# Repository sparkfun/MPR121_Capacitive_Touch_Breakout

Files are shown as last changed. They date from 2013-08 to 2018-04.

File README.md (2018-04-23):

**NOTE:** *This product has been retired from our catalog. If you are looking for more up-to-date info, please check out some of these resources to see how other users are still hacking and improving on this product.*
* *[SparkFun Forum](https://forum.sparkfun.com/)*
* *[Comments Here on GitHub](https://github.com/sparkfun/MPR121_Capacitive_Touch_Breakout/issues)*
* *[IRC Channel](https://www.sparkfun.com/news/263)*

MPR121 Capacitive Touch Sensor Breakout Board
=============================================

[MPR121 Breakout Board  
*MPR121 Capacitive Touch Sensor Breakout Board (SEN-09695)*](https://www.sparkfun.com/products/9695)

This is a breakout  board for the MPR121QR2. It is a capacitive touch sensor controller driven by an I2C interface. The chip can control
up to twelve individual electrodes, as well as a simulated thirteenth electrode. 

Repository Contents
-------------------
* **/Firmware** - Example Arduino Sketch
* **/Hardware** - All Eagle design files (.brd, .sch)

License Information
-------------------
The hardware is released under [Creative Commons Share-alike 3.0](http://creativecommons.org/licenses/by-sa/3.0/).  
All other code is open source so please feel free to do anything you want with it; you buy me a beer if you use this and we meet someday ([Beerware license](http://en.wikipedia.org/wiki/Beerware)).

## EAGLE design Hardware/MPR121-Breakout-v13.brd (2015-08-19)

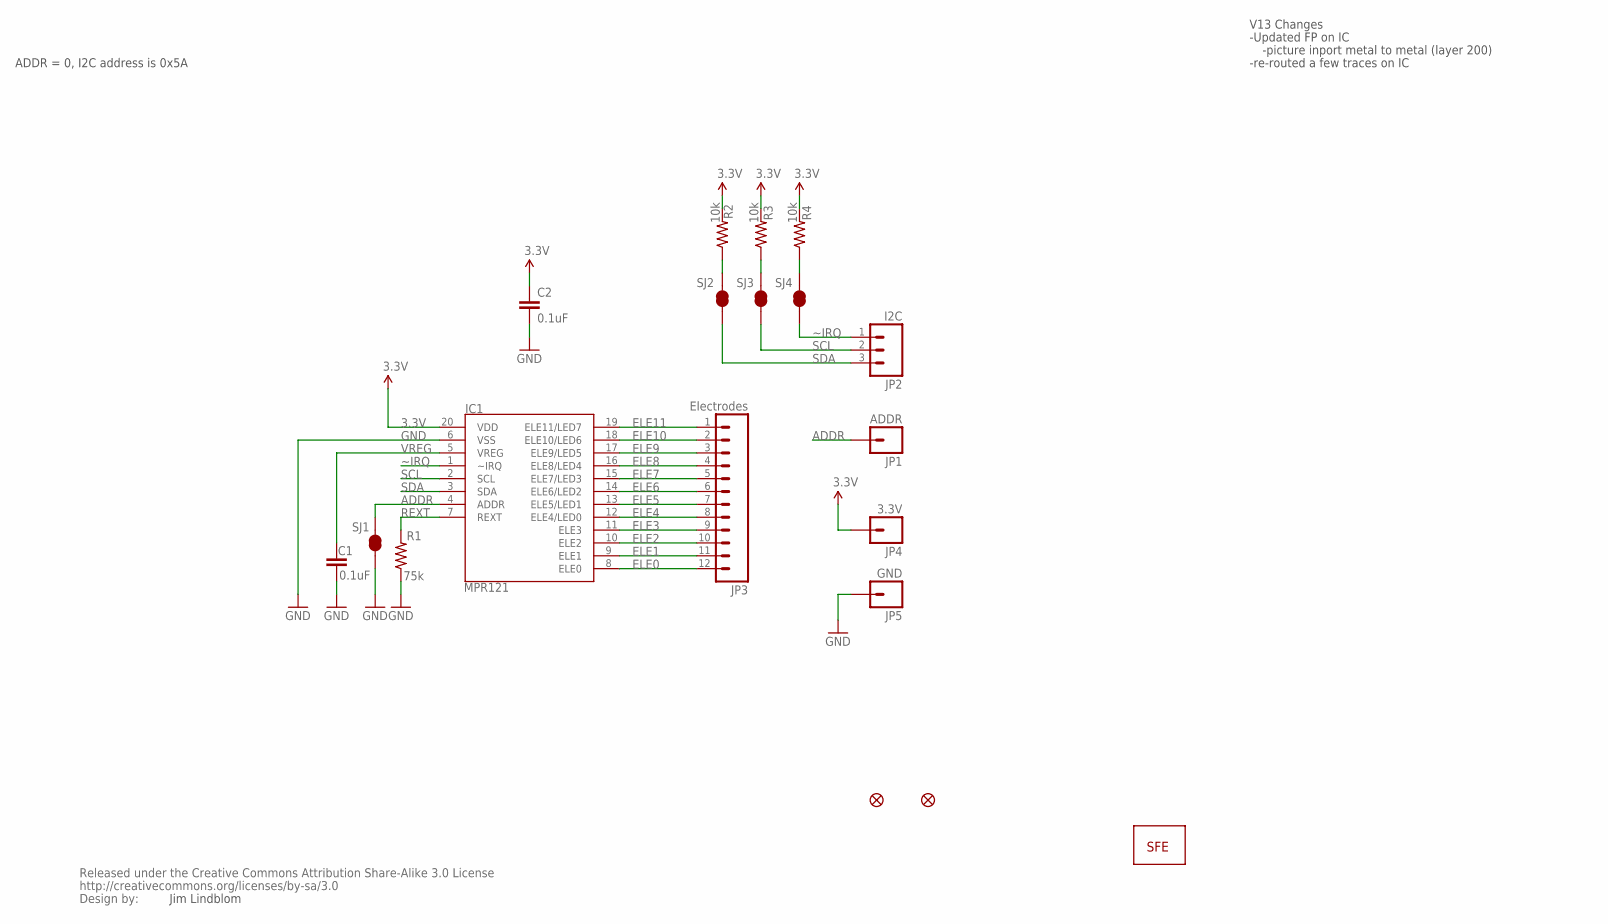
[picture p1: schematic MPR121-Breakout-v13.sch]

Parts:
C1, C2: 0.1uF; 0603-CAP
IC1: MPR121; QFN-20-0.4MM-V2
JP1: ADDR; 1X01
JP2: I2C; 1X03
JP3: Electrodes; 1X12
JP4: 3.3V; 1X01
JP5: GND; 1X01
JP7: LOGO-SFENEW; SFE-NEW-WEBLOGO
JP8, JP9: FIDUCIAL1X2; FIDUCIAL-1X2
R1: 75k; 0603-RES
R2, R3, R4: 10k; 0603-RES
SJ1, SJ2, SJ3, SJ4: SOLDERJUMPERTRACE; SJ_2S-TRACE
U$1: CREATIVE_COMMONS

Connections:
3.3V: C2.1, IC1.20 (VDD), JP4.1, R2.2, R3.2, R4.2
ADDR: IC1.4 (ADDR), JP1.1, SJ1.2
ELE0: IC1.8 (ELE0), JP3.12
ELE1: IC1.9 (ELE1), JP3.11
ELE2: IC1.10 (ELE2), JP3.10
ELE3: IC1.11 (ELE3), JP3.9
ELE4: IC1.12 (ELE4/LED0), JP3.8
ELE5: IC1.13 (ELE5/LED1), JP3.7
ELE6: IC1.14 (ELE6/LED2), JP3.6
ELE7: IC1.15 (ELE7/LED3), JP3.5
ELE8: IC1.16 (ELE8/LED4), JP3.4
ELE9: IC1.17 (ELE9/LED5), JP3.3
ELE10: IC1.18 (ELE10/LED6), JP3.2
ELE11: IC1.19 (ELE11/LED7), JP3.1
GND: C1.2, C2.2, IC1.6 (VSS), JP5.1, R1.1, SJ1.1
REXT: IC1.7 (REXT), R1.2
SCL: IC1.2 (SCL), JP2.2, SJ3.1
SCL_PU: R3.1, SJ3.2
SDA: IC1.3 (SDA), JP2.3, SJ2.1
SDA_PU: R2.1, SJ2.2
VREG: C1.1, IC1.5 (VREG)
~IRQ: IC1.1 (~IRQ), JP2.1, SJ4.1
~IRQ_PU: R4.1, SJ4.2

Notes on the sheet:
ADDR = 0, I2C address is 0x5A
Jim Lindblom
V13 Changes
-Updated FP on IC
-picture inport metal to metal (layer 200)
-re-routed a few traces on IC

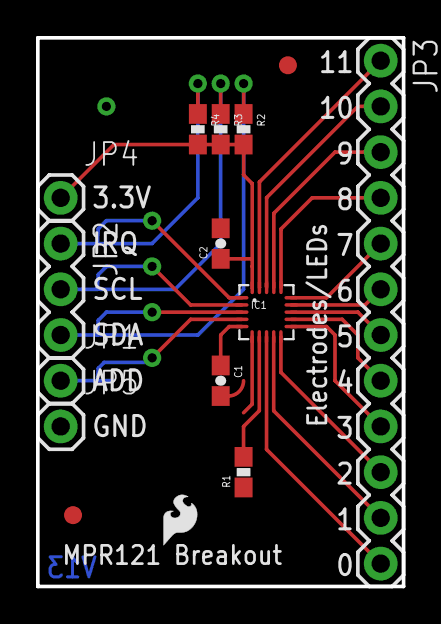
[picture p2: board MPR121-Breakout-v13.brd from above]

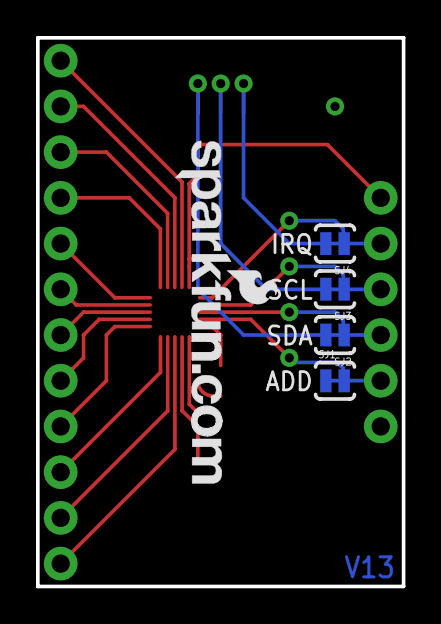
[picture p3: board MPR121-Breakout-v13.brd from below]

Board: 2 copper layers, 20.3 x 30.5 mm, 21 parts (5 on the bottom side), 23 nets.

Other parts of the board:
JP6: LOGO-SFESK; SFE-LOGO-FLAME

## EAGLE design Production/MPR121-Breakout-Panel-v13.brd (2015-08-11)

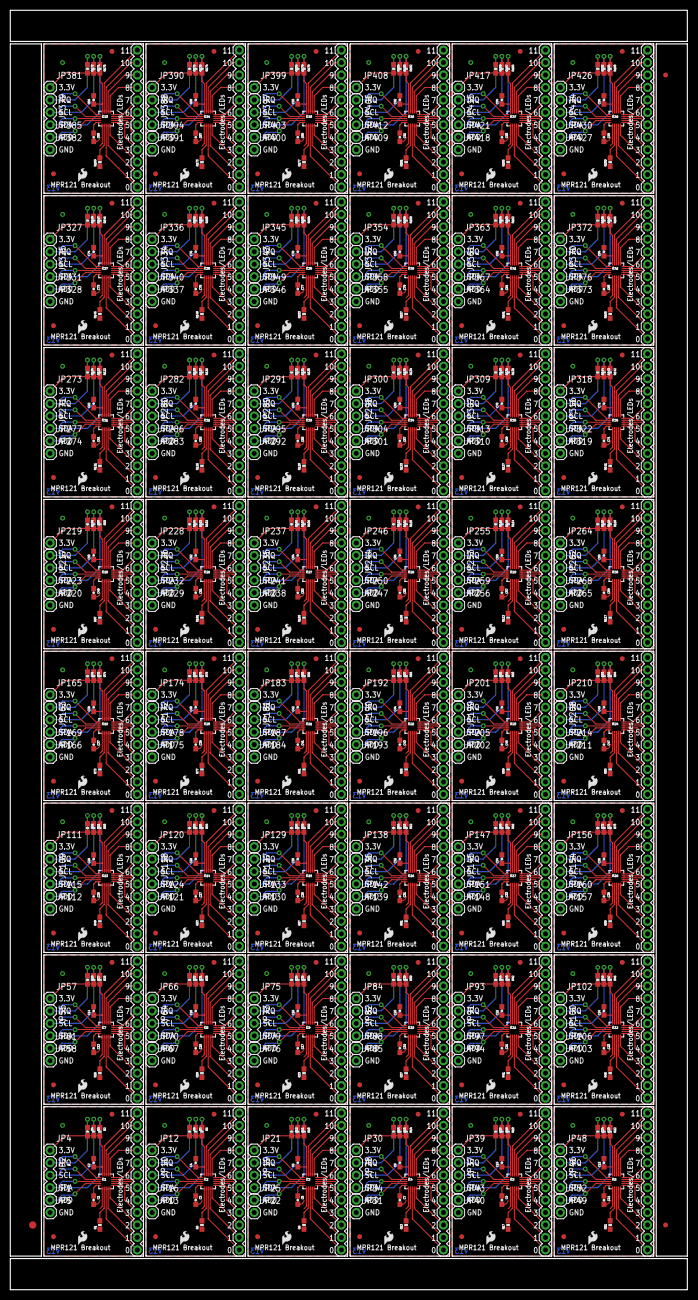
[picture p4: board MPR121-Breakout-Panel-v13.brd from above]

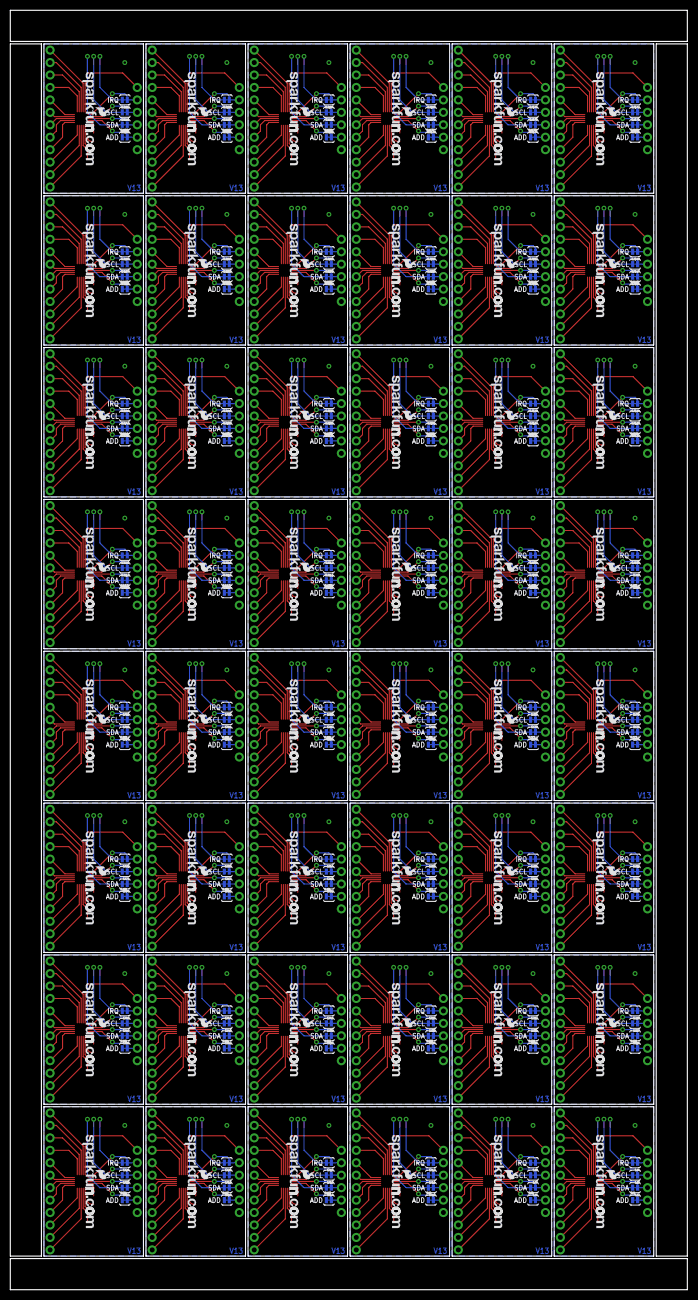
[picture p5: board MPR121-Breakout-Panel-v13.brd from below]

Board: 2 copper layers, 138.2 x 261.1 mm, 963 parts (240 on the bottom side), 1104 nets.

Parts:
C1, C2, C3, C4, C5, C6, C7, C8, C9, C10, C11, C12, C13, C14, C15, C16, C17, C18, C19, C20, C21, C22, C23, C24, C25, C26, C27, C28, C29, C30, C31, C32, C33, C34, C35, C36, C37, C38, C39, C40, C41, C42, C43, C44, C45, C46, C47, C48, C49, C50, C51, C52, C53, C54, C55, C56, C57, C58, C59, C60, C61, C62, C63, C64, C65, C66, C67, C68, C69, C70, C71, C72, C73, C74, C75, C76, C77, C78, C79, C80, C81, C82, C83, C84, C85, C86, C87, C88, C89, C90, C91, C92, C93, C94, C95, C96: 0.1uF; 0603-CAP
E$1: FIDUCIAL-1.5X3
E$4, E$5: FIDUCIAL-1X2
IC1, IC2, IC3, IC4, IC5, IC6, IC7, IC8, IC9, IC10, IC11, IC12, IC13, IC14, IC15, IC16, IC17, IC18, IC19, IC20, IC21, IC22, IC23, IC24, IC25, IC26, IC27, IC28, IC29, IC30, IC31, IC32, IC33, IC34, IC35, IC36, IC37, IC38, IC39, IC40, IC41, IC42, IC43, IC44, IC45, IC46, IC47, IC48: MPR121; QFN-20-0.4MM-V2
JP1, JP16, JP25, JP34, JP43, JP52, JP61, JP70, JP79, JP88, JP97, JP106, JP115, JP124, JP133, JP142, JP151, JP160, JP169, JP178, JP187, JP196, JP205, JP214, JP223, JP232, JP241, JP250, JP259, JP268, JP277, JP286, JP295, JP304, JP313, JP322, JP331, JP340, JP349, JP358, JP367, JP376, JP385, JP394, JP403, JP412, JP421, JP430: ADDR; 1X01
JP2, JP10, JP19, JP28, JP37, JP46, JP55, JP64, JP73, JP82, JP91, JP100, JP109, JP118, JP127, JP136, JP145, JP154, JP163, JP172, JP181, JP190, JP199, JP208, JP217, JP226, JP235, JP244, JP253, JP262, JP271, JP280, JP289, JP298, JP307, JP316, JP325, JP334, JP343, JP352, JP361, JP370, JP379, JP388, JP397, JP406, JP415, JP424: I2C; 1X03
JP3, JP11, JP20, JP29, JP38, JP47, JP56, JP65, JP74, JP83, JP92, JP101, JP110, JP119, JP128, JP137, JP146, JP155, JP164, JP173, JP182, JP191, JP200, JP209, JP218, JP227, JP236, JP245, JP254, JP263, JP272, JP281, JP290, JP299, JP308, JP317, JP326, JP335, JP344, JP353, JP362, JP371, JP380, JP389, JP398, JP407, JP416, JP425: Electrodes; 1X12
JP4, JP12, JP21, JP30, JP39, JP48, JP57, JP66, JP75, JP84, JP93, JP102, JP111, JP120, JP129, JP138, JP147, JP156, JP165, JP174, JP183, JP192, JP201, JP210, JP219, JP228, JP237, JP246, JP255, JP264, JP273, JP282, JP291, JP300, JP309, JP318, JP327, JP336, JP345, JP354, JP363, JP372, JP381, JP390, JP399, JP408, JP417, JP426: 3.3V; 1X01
JP5, JP13, JP22, JP31, JP40, JP49, JP58, JP67, JP76, JP85, JP94, JP103, JP112, JP121, JP130, JP139, JP148, JP157, JP166, JP175, JP184, JP193, JP202, JP211, JP220, JP229, JP238, JP247, JP256, JP265, JP274, JP283, JP292, JP301, JP310, JP319, JP328, JP337, JP346, JP355, JP364, JP373, JP382, JP391, JP400, JP409, JP418, JP427: GND; 1X01
JP6, JP14, JP23, JP32, JP41, JP50, JP59, JP68, JP77, JP86, JP95, JP104, JP113, JP122, JP131, JP140, JP149, JP158, JP167, JP176, JP185, JP194, JP203, JP212, JP221, JP230, JP239, JP248, JP257, JP266, JP275, JP284, JP293, JP302, JP311, JP320, JP329, JP338, JP347, JP356, JP365, JP374, JP383, JP392, JP401, JP410, JP419, JP428: LOGO-SFESK; SFE-LOGO-FLAME
JP7, JP15, JP24, JP33, JP42, JP51, JP60, JP69, JP78, JP87, JP96, JP105, JP114, JP123, JP132, JP141, JP150, JP159, JP168, JP177, JP186, JP195, JP204, JP213, JP222, JP231, JP240, JP249, JP258, JP267, JP276, JP285, JP294, JP303, JP312, JP321, JP330, JP339, JP348, JP357, JP366, JP375, JP384, JP393, JP402, JP411, JP420, JP429: LOGO-SFENEW; SFE-NEW-WEBLOGO
JP8, JP9, JP17, JP18, JP26, JP27, JP35, JP36, JP44, JP45, JP53, JP54, JP62, JP63, JP71, JP72, JP80, JP81, JP89, JP90, JP98, JP99, JP107, JP108, JP116, JP117, JP125, JP126, JP134, JP135, JP143, JP144, JP152, JP153, JP161, JP162, JP170, JP171, JP179, JP180, JP188, JP189, JP197, JP198, JP206, JP207, JP215, JP216, JP224, JP225, JP233, JP234, JP242, JP243, JP251, JP252, JP260, JP261, JP269, JP270, JP278, JP279, JP287, JP288, JP296, JP297, JP305, JP306, JP314, JP315, JP323, JP324, JP332, JP333, JP341, JP342, JP350, JP351, JP359, JP360, JP368, JP369, JP377, JP378, JP386, JP387, JP395, JP396, JP404, JP405, JP413, JP414, JP422, JP423, JP431, JP432: FIDUCIAL1X2; FIDUCIAL-1X2
R1, R5, R9, R13, R17, R21, R25, R29, R33, R37, R41, R45, R49, R53, R57, R61, R65, R69, R73, R77, R81, R85, R89, R93, R97, R101, R105, R109, R113, R117, R121, R125, R129, R133, R137, R141, R145, R149, R153, R157, R161, R165, R169, R173, R177, R181, R185, R189: 75k; 0603-RES
R2, R3, R4, R6, R7, R8, R10, R11, R12, R14, R15, R16, R18, R19, R20, R22, R23, R24, R26, R27, R28, R30, R31, R32, R34, R35, R36, R38, R39, R40, R42, R43, R44, R46, R47, R48, R50, R51, R52, R54, R55, R56, R58, R59, R60, R62, R63, R64, R66, R67, R68, R70, R71, R72, R74, R75, R76, R78, R79, R80, R82, R83, R84, R86, R87, R88, R90, R91, R92, R94, R95, R96, R98, R99, R100, R102, R103, R104, R106, R107, R108, R110, R111, R112, R114, R115, R116, R118, R119, R120, R122, R123, R124, R126, R127, R128, R130, R131, R132, R134, R135, R136, R138, R139, R140, R142, R143, R144, R146, R147, R148, R150, R151, R152, R154, R155, R156, R158, R159, R160, R162, R163, R164, R166, R167, R168, R170, R171, R172, R174, R175, R176, R178, R179, R180, R182, R183, R184, R186, R187, R188, R190, R191, R192: 10k; 0603-RES
SJ1, SJ2, SJ3, SJ4, SJ5, SJ6, SJ7, SJ8, SJ9, SJ10, SJ11, SJ12, SJ13, SJ14, SJ15, SJ16, SJ17, SJ18, SJ19, SJ20, SJ21, SJ22, SJ23, SJ24, SJ25, SJ26, SJ27, SJ28, SJ29, SJ30, SJ31, SJ32, SJ33, SJ34, SJ35, SJ36, SJ37, SJ38, SJ39, SJ40, SJ41, SJ42, SJ43, SJ44, SJ45, SJ46, SJ47, SJ48, SJ49, SJ50, SJ51, SJ52, SJ53, SJ54, SJ55, SJ56, SJ57, SJ58, SJ59, SJ60, SJ61, SJ62, SJ63, SJ64, SJ65, SJ66, SJ67, SJ68, SJ69, SJ70, SJ71, SJ72, SJ73, SJ74, SJ75, SJ76, SJ77, SJ78, SJ79, SJ80, SJ81, SJ82, SJ83, SJ84, SJ85, SJ86, SJ87, SJ88, SJ89, SJ90, SJ91, SJ92, SJ93, SJ94, SJ95, SJ96, SJ97, SJ98, SJ99, SJ100, SJ101, SJ102, SJ103, SJ104, SJ105, SJ106, SJ107, SJ108, SJ109, SJ110, SJ111, SJ112, SJ113, SJ114, SJ115, SJ116, SJ117, SJ118, SJ119, SJ120, SJ121, SJ122, SJ123, SJ124, SJ125, SJ126, SJ127, SJ128, SJ129, SJ130, SJ131, SJ132, SJ133, SJ134, SJ135, SJ136, SJ137, SJ138, SJ139, SJ140, SJ141, SJ142, SJ143, SJ144, SJ145, SJ146, SJ147, SJ148, SJ149, SJ150, SJ151, SJ152, SJ153, SJ154, SJ155, SJ156, SJ157, SJ158, SJ159, SJ160, SJ161, SJ162, SJ163, SJ164, SJ165, SJ166, SJ167, SJ168, SJ169, SJ170, SJ171, SJ172, SJ173, SJ174, SJ175, SJ176, SJ177, SJ178, SJ179, SJ180, SJ181, SJ182, SJ183, SJ184, SJ185, SJ186, SJ187, SJ188, SJ189, SJ190, SJ191, SJ192: SOLDERJUMPERTRACE; SJ_2S-TRACE

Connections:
3.3V: C2.1, IC1.20, JP4.1, R2.2, R3.2, R4.2
3.3V1: C4.1, IC2.20, JP12.1, R6.2, R7.2, R8.2
3.3V2: C6.1, IC3.20, JP21.1, R10.2, R11.2, R12.2
3.3V3: C8.1, IC4.20, JP30.1, R14.2, R15.2, R16.2
3.3V4: C10.1, IC5.20, JP39.1, R18.2, R19.2, R20.2
3.3V5: C12.1, IC6.20, JP48.1, R22.2, R23.2, R24.2
3.3V6: C14.1, IC7.20, JP57.1, R26.2, R27.2, R28.2
3.3V7: C16.1, IC8.20, JP66.1, R30.2, R31.2, R32.2
3.3V8: C18.1, IC9.20, JP75.1, R34.2, R35.2, R36.2
3.3V9: C20.1, IC10.20, JP84.1, R38.2, R39.2, R40.2
3.3V10: C22.1, IC11.20, JP93.1, R42.2, R43.2, R44.2
3.3V11: C24.1, IC12.20, JP102.1, R46.2, R47.2, R48.2
3.3V12: C26.1, IC13.20, JP111.1, R50.2, R51.2, R52.2
3.3V13: C28.1, IC14.20, JP120.1, R54.2, R55.2, R56.2
3.3V14: C30.1, IC15.20, JP129.1, R58.2, R59.2, R60.2
3.3V15: C32.1, IC16.20, JP138.1, R62.2, R63.2, R64.2
3.3V16: C34.1, IC17.20, JP147.1, R66.2, R67.2, R68.2
3.3V17: C36.1, IC18.20, JP156.1, R70.2, R71.2, R72.2
3.3V18: C38.1, IC19.20, JP165.1, R74.2, R75.2, R76.2
3.3V19: C40.1, IC20.20, JP174.1, R78.2, R79.2, R80.2
3.3V20: C42.1, IC21.20, JP183.1, R82.2, R83.2, R84.2
3.3V21: C44.1, IC22.20, JP192.1, R86.2, R87.2, R88.2
3.3V22: C46.1, IC23.20, JP201.1, R90.2, R91.2, R92.2
3.3V23: C48.1, IC24.20, JP210.1, R94.2, R95.2, R96.2
3.3V24: C50.1, IC25.20, JP219.1, R98.2, R99.2, R100.2
3.3V25: C52.1, IC26.20, JP228.1, R102.2, R103.2, R104.2
3.3V26: C54.1, IC27.20, JP237.1, R106.2, R107.2, R108.2
3.3V27: C56.1, IC28.20, JP246.1, R110.2, R111.2, R112.2
3.3V28: C58.1, IC29.20, JP255.1, R114.2, R115.2, R116.2
3.3V29: C60.1, IC30.20, JP264.1, R118.2, R119.2, R120.2
3.3V30: C62.1, IC31.20, JP273.1, R122.2, R123.2, R124.2
3.3V31: C64.1, IC32.20, JP282.1, R126.2, R127.2, R128.2
3.3V32: C66.1, IC33.20, JP291.1, R130.2, R131.2, R132.2
3.3V33: C68.1, IC34.20, JP300.1, R134.2, R135.2, R136.2
3.3V34: C70.1, IC35.20, JP309.1, R138.2, R139.2, R140.2
3.3V35: C72.1, IC36.20, JP318.1, R142.2, R143.2, R144.2
3.3V36: C74.1, IC37.20, JP327.1, R146.2, R147.2, R148.2
3.3V37: C76.1, IC38.20, JP336.1, R150.2, R151.2, R152.2
3.3V38: C78.1, IC39.20, JP345.1, R154.2, R155.2, R156.2
3.3V39: C80.1, IC40.20, JP354.1, R158.2, R159.2, R160.2
3.3V40: C82.1, IC41.20, JP363.1, R162.2, R163.2, R164.2
3.3V41: C84.1, IC42.20, JP372.1, R166.2, R167.2, R168.2
3.3V42: C86.1, IC43.20, JP381.1, R170.2, R171.2, R172.2
3.3V43: C88.1, IC44.20, JP390.1, R174.2, R175.2, R176.2
3.3V44: C90.1, IC45.20, JP399.1, R178.2, R179.2, R180.2
3.3V45: C92.1, IC46.20, JP408.1, R182.2, R183.2, R184.2
3.3V46: C94.1, IC47.20, JP417.1, R186.2, R187.2, R188.2
3.3V47: C96.1, IC48.20, JP426.1, R190.2, R191.2, R192.2
ADDR: IC1.4, JP1.1, SJ1.2
ADDR1: IC2.4, JP16.1, SJ5.2
ADDR2: IC3.4, JP25.1, SJ9.2
ADDR3: IC4.4, JP34.1, SJ13.2
ADDR4: IC5.4, JP43.1, SJ17.2
ADDR5: IC6.4, JP52.1, SJ21.2
ADDR6: IC7.4, JP61.1, SJ25.2
ADDR7: IC8.4, JP70.1, SJ29.2
ADDR8: IC9.4, JP79.1, SJ33.2
ADDR9: IC10.4, JP88.1, SJ37.2
ADDR10: IC11.4, JP97.1, SJ41.2
ADDR11: IC12.4, JP106.1, SJ45.2
ADDR12: IC13.4, JP115.1, SJ49.2
ADDR13: IC14.4, JP124.1, SJ53.2
ADDR14: IC15.4, JP133.1, SJ57.2
ADDR15: IC16.4, JP142.1, SJ61.2
ADDR16: IC17.4, JP151.1, SJ65.2
ADDR17: IC18.4, JP160.1, SJ69.2
ADDR18: IC19.4, JP169.1, SJ73.2
ADDR19: IC20.4, JP178.1, SJ77.2
ADDR20: IC21.4, JP187.1, SJ81.2
ADDR21: IC22.4, JP196.1, SJ85.2
ADDR22: IC23.4, JP205.1, SJ89.2
ADDR23: IC24.4, JP214.1, SJ93.2
ADDR24: IC25.4, JP223.1, SJ97.2
ADDR25: IC26.4, JP232.1, SJ101.2
ADDR26: IC27.4, JP241.1, SJ105.2
ADDR27: IC28.4, JP250.1, SJ109.2
ADDR28: IC29.4, JP259.1, SJ113.2
ADDR29: IC30.4, JP268.1, SJ117.2
ADDR30: IC31.4, JP277.1, SJ121.2
ADDR31: IC32.4, JP286.1, SJ125.2
ADDR32: IC33.4, JP295.1, SJ129.2
ADDR33: IC34.4, JP304.1, SJ133.2
ADDR34: IC35.4, JP313.1, SJ137.2
ADDR35: IC36.4, JP322.1, SJ141.2
ADDR36: IC37.4, JP331.1, SJ145.2
ADDR37: IC38.4, JP340.1, SJ149.2
ADDR38: IC39.4, JP349.1, SJ153.2
ADDR39: IC40.4, JP358.1, SJ157.2
ADDR40: IC41.4, JP367.1, SJ161.2
ADDR41: IC42.4, JP376.1, SJ165.2
ADDR42: IC43.4, JP385.1, SJ169.2
ADDR43: IC44.4, JP394.1, SJ173.2
ADDR44: IC45.4, JP403.1, SJ177.2
ADDR45: IC46.4, JP412.1, SJ181.2
ADDR46: IC47.4, JP421.1, SJ185.2
ADDR47: IC48.4, JP430.1, SJ189.2
ELE0: IC1.8, JP3.12
ELE1: IC1.9, JP3.11
ELE2: IC1.10, JP3.10
ELE3: IC1.11, JP3.9
ELE4: IC1.12, JP3.8
ELE5: IC1.13, JP3.7
ELE6: IC1.14, JP3.6
ELE7: IC1.15, JP3.5
ELE8: IC1.16, JP3.4
ELE9: IC1.17, JP3.3
ELE10: IC1.18, JP3.2
ELE11: IC1.19, JP3.1
ELE12: IC2.19, JP11.1
ELE13: IC2.18, JP11.2
ELE14: IC2.17, JP11.3
ELE15: IC2.16, JP11.4
ELE16: IC2.15, JP11.5
ELE17: IC2.14, JP11.6
ELE18: IC2.13, JP11.7
ELE19: IC2.12, JP11.8
ELE20: IC2.11, JP11.9
ELE21: IC2.10, JP11.10
ELE22: IC2.9, JP11.11
ELE23: IC2.8, JP11.12
ELE24: IC3.19, JP20.1
ELE25: IC3.18, JP20.2
ELE26: IC3.17, JP20.3
ELE27: IC3.16, JP20.4
ELE28: IC3.15, JP20.5
ELE29: IC3.14, JP20.6
ELE30: IC3.13, JP20.7
ELE31: IC3.12, JP20.8
ELE32: IC3.11, JP20.9
ELE33: IC3.10, JP20.10
ELE34: IC3.9, JP20.11
ELE35: IC3.8, JP20.12
ELE36: IC4.19, JP29.1
ELE37: IC4.18, JP29.2
ELE38: IC4.17, JP29.3
ELE39: IC4.16, JP29.4
ELE40: IC4.15, JP29.5
ELE41: IC4.14, JP29.6
ELE42: IC4.13, JP29.7
ELE43: IC4.12, JP29.8
ELE44: IC4.11, JP29.9
ELE45: IC4.10, JP29.10
ELE46: IC4.9, JP29.11
ELE47: IC4.8, JP29.12
ELE48: IC5.19, JP38.1
ELE49: IC5.18, JP38.2
ELE50: IC5.17, JP38.3
ELE51: IC5.16, JP38.4
ELE52: IC5.15, JP38.5
ELE53: IC5.14, JP38.6
ELE54: IC5.13, JP38.7
ELE55: IC5.12, JP38.8
ELE56: IC5.11, JP38.9
ELE57: IC5.10, JP38.10
ELE58: IC5.9, JP38.11
ELE59: IC5.8, JP38.12
ELE60: IC6.19, JP47.1
ELE61: IC6.18, JP47.2
ELE62: IC6.17, JP47.3
ELE63: IC6.16, JP47.4
ELE64: IC6.15, JP47.5
ELE65: IC6.14, JP47.6
ELE66: IC6.13, JP47.7
ELE67: IC6.12, JP47.8
ELE68: IC6.11, JP47.9
ELE69: IC6.10, JP47.10
ELE70: IC6.9, JP47.11
ELE71: IC6.8, JP47.12
ELE72: IC7.19, JP56.1
ELE73: IC7.18, JP56.2
ELE74: IC7.17, JP56.3
ELE75: IC7.16, JP56.4
ELE76: IC7.15, JP56.5
ELE77: IC7.14, JP56.6
ELE78: IC7.13, JP56.7
ELE79: IC7.12, JP56.8
ELE80: IC7.11, JP56.9
ELE81: IC7.10, JP56.10
ELE82: IC7.9, JP56.11
ELE83: IC7.8, JP56.12
ELE84: IC8.19, JP65.1
ELE85: IC8.18, JP65.2
ELE86: IC8.17, JP65.3
ELE87: IC8.16, JP65.4
ELE88: IC8.15, JP65.5
ELE89: IC8.14, JP65.6
ELE90: IC8.13, JP65.7
ELE91: IC8.12, JP65.8
ELE92: IC8.11, JP65.9
ELE93: IC8.10, JP65.10
ELE94: IC8.9, JP65.11
ELE95: IC8.8, JP65.12
ELE96: IC9.19, JP74.1
ELE97: IC9.18, JP74.2
ELE98: IC9.17, JP74.3
ELE99: IC9.16, JP74.4
ELE100: IC9.15, JP74.5
ELE101: IC9.14, JP74.6
ELE102: IC9.13, JP74.7
ELE103: IC9.12, JP74.8
ELE104: IC9.11, JP74.9
ELE105: IC9.10, JP74.10
ELE106: IC9.9, JP74.11
ELE107: IC9.8, JP74.12
ELE108: IC10.19, JP83.1
ELE109: IC10.18, JP83.2
ELE110: IC10.17, JP83.3
ELE111: IC10.16, JP83.4
ELE112: IC10.15, JP83.5
ELE113: IC10.14, JP83.6
ELE114: IC10.13, JP83.7
ELE115: IC10.12, JP83.8
ELE116: IC10.11, JP83.9
ELE117: IC10.10, JP83.10
ELE118: IC10.9, JP83.11
ELE119: IC10.8, JP83.12
ELE120: IC11.19, JP92.1
ELE121: IC11.18, JP92.2
ELE122: IC11.17, JP92.3
ELE123: IC11.16, JP92.4
ELE124: IC11.15, JP92.5
ELE125: IC11.14, JP92.6
ELE126: IC11.13, JP92.7
ELE127: IC11.12, JP92.8
ELE128: IC11.11, JP92.9
ELE129: IC11.10, JP92.10
ELE130: IC11.9, JP92.11
ELE131: IC11.8, JP92.12
ELE132: IC12.19, JP101.1
ELE133: IC12.18, JP101.2
ELE134: IC12.17, JP101.3
ELE135: IC12.16, JP101.4
ELE136: IC12.15, JP101.5
ELE137: IC12.14, JP101.6
ELE138: IC12.13, JP101.7
ELE139: IC12.12, JP101.8
ELE140: IC12.11, JP101.9
ELE141: IC12.10, JP101.10
ELE142: IC12.9, JP101.11
ELE143: IC12.8, JP101.12
ELE144: IC13.19, JP110.1
ELE145: IC13.18, JP110.2
ELE146: IC13.17, JP110.3
ELE147: IC13.16, JP110.4
ELE148: IC13.15, JP110.5
ELE149: IC13.14, JP110.6
ELE150: IC13.13, JP110.7
ELE151: IC13.12, JP110.8
ELE152: IC13.11, JP110.9
ELE153: IC13.10, JP110.10
ELE154: IC13.9, JP110.11
ELE155: IC13.8, JP110.12
ELE156: IC14.19, JP119.1
ELE157: IC14.18, JP119.2
ELE158: IC14.17, JP119.3
ELE159: IC14.16, JP119.4
ELE160: IC14.15, JP119.5
ELE161: IC14.14, JP119.6
ELE162: IC14.13, JP119.7
ELE163: IC14.12, JP119.8
ELE164: IC14.11, JP119.9
ELE165: IC14.10, JP119.10
ELE166: IC14.9, JP119.11
ELE167: IC14.8, JP119.12
ELE168: IC15.19, JP128.1
ELE169: IC15.18, JP128.2
ELE170: IC15.17, JP128.3
ELE171: IC15.16, JP128.4
ELE172: IC15.15, JP128.5
ELE173: IC15.14, JP128.6
ELE174: IC15.13, JP128.7
ELE175: IC15.12, JP128.8
ELE176: IC15.11, JP128.9
ELE177: IC15.10, JP128.10
ELE178: IC15.9, JP128.11
ELE179: IC15.8, JP128.12
ELE180: IC16.19, JP137.1
ELE181: IC16.18, JP137.2
ELE182: IC16.17, JP137.3
ELE183: IC16.16, JP137.4
ELE184: IC16.15, JP137.5
ELE185: IC16.14, JP137.6
ELE186: IC16.13, JP137.7
ELE187: IC16.12, JP137.8
ELE188: IC16.11, JP137.9
ELE189: IC16.10, JP137.10
ELE190: IC16.9, JP137.11
ELE191: IC16.8, JP137.12
ELE192: IC17.19, JP146.1
ELE193: IC17.18, JP146.2
ELE194: IC17.17, JP146.3
ELE195: IC17.16, JP146.4
ELE196: IC17.15, JP146.5
ELE197: IC17.14, JP146.6
ELE198: IC17.13, JP146.7
ELE199: IC17.12, JP146.8
ELE200: IC17.11, JP146.9
ELE201: IC17.10, JP146.10
ELE202: IC17.9, JP146.11
ELE203: IC17.8, JP146.12
ELE204: IC18.19, JP155.1
ELE205: IC18.18, JP155.2
ELE206: IC18.17, JP155.3
ELE207: IC18.16, JP155.4
ELE208: IC18.15, JP155.5
ELE209: IC18.14, JP155.6
ELE210: IC18.13, JP155.7
ELE211: IC18.12, JP155.8
ELE212: IC18.11, JP155.9
ELE213: IC18.10, JP155.10
ELE214: IC18.9, JP155.11
ELE215: IC18.8, JP155.12
ELE216: IC19.19, JP164.1
ELE217: IC19.18, JP164.2
ELE218: IC19.17, JP164.3
ELE219: IC19.16, JP164.4
ELE220: IC19.15, JP164.5
ELE221: IC19.14, JP164.6
ELE222: IC19.13, JP164.7
ELE223: IC19.12, JP164.8
ELE224: IC19.11, JP164.9
ELE225: IC19.10, JP164.10
ELE226: IC19.9, JP164.11
ELE227: IC19.8, JP164.12
ELE228: IC20.19, JP173.1
ELE229: IC20.18, JP173.2
ELE230: IC20.17, JP173.3
ELE231: IC20.16, JP173.4
ELE232: IC20.15, JP173.5
ELE233: IC20.14, JP173.6
ELE234: IC20.13, JP173.7
ELE235: IC20.12, JP173.8
ELE236: IC20.11, JP173.9
ELE237: IC20.10, JP173.10
ELE238: IC20.9, JP173.11
ELE239: IC20.8, JP173.12
ELE240: IC21.19, JP182.1
ELE241: IC21.18, JP182.2
ELE242: IC21.17, JP182.3
ELE243: IC21.16, JP182.4
ELE244: IC21.15, JP182.5
ELE245: IC21.14, JP182.6
ELE246: IC21.13, JP182.7
ELE247: IC21.12, JP182.8
ELE248: IC21.11, JP182.9
ELE249: IC21.10, JP182.10
ELE250: IC21.9, JP182.11
ELE251: IC21.8, JP182.12
ELE252: IC22.19, JP191.1
ELE253: IC22.18, JP191.2
ELE254: IC22.17, JP191.3
ELE255: IC22.16, JP191.4
ELE256: IC22.15, JP191.5
ELE257: IC22.14, JP191.6
ELE258: IC22.13, JP191.7
ELE259: IC22.12, JP191.8
ELE260: IC22.11, JP191.9
ELE261: IC22.10, JP191.10
ELE262: IC22.9, JP191.11
ELE263: IC22.8, JP191.12
ELE264: IC23.19, JP200.1
ELE265: IC23.18, JP200.2
ELE266: IC23.17, JP200.3
ELE267: IC23.16, JP200.4
ELE268: IC23.15, JP200.5
ELE269: IC23.14, JP200.6
ELE270: IC23.13, JP200.7
ELE271: IC23.12, JP200.8
ELE272: IC23.11, JP200.9
ELE273: IC23.10, JP200.10
ELE274: IC23.9, JP200.11
ELE275: IC23.8, JP200.12
ELE276: IC24.19, JP209.1
ELE277: IC24.18, JP209.2
ELE278: IC24.17, JP209.3
ELE279: IC24.16, JP209.4
ELE280: IC24.15, JP209.5
ELE281: IC24.14, JP209.6
ELE282: IC24.13, JP209.7
ELE283: IC24.12, JP209.8
ELE284: IC24.11, JP209.9
ELE285: IC24.10, JP209.10
ELE286: IC24.9, JP209.11
ELE287: IC24.8, JP209.12
ELE288: IC25.19, JP218.1
ELE289: IC25.18, JP218.2
ELE290: IC25.17, JP218.3
ELE291: IC25.16, JP218.4
ELE292: IC25.15, JP218.5
ELE293: IC25.14, JP218.6
ELE294: IC25.13, JP218.7
ELE295: IC25.12, JP218.8
ELE296: IC25.11, JP218.9
ELE297: IC25.10, JP218.10
ELE298: IC25.9, JP218.11
ELE299: IC25.8, JP218.12
ELE300: IC26.19, JP227.1
ELE301: IC26.18, JP227.2
ELE302: IC26.17, JP227.3
ELE303: IC26.16, JP227.4
ELE304: IC26.15, JP227.5
ELE305: IC26.14, JP227.6
ELE306: IC26.13, JP227.7
ELE307: IC26.12, JP227.8
ELE308: IC26.11, JP227.9
ELE309: IC26.10, JP227.10
ELE310: IC26.9, JP227.11
ELE311: IC26.8, JP227.12
ELE312: IC27.19, JP236.1
ELE313: IC27.18, JP236.2
ELE314: IC27.17, JP236.3
ELE315: IC27.16, JP236.4
ELE316: IC27.15, JP236.5
ELE317: IC27.14, JP236.6
ELE318: IC27.13, JP236.7
ELE319: IC27.12, JP236.8
ELE320: IC27.11, JP236.9
ELE321: IC27.10, JP236.10
ELE322: IC27.9, JP236.11
ELE323: IC27.8, JP236.12
ELE324: IC28.19, JP245.1
ELE325: IC28.18, JP245.2
ELE326: IC28.17, JP245.3
ELE327: IC28.16, JP245.4
ELE328: IC28.15, JP245.5
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

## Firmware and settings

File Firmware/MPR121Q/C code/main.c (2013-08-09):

/*
    MPR121 Test Code
	April 8, 2010
	by: Jim Lindblom
	
	This example code will both sense for touches, and drive LEDs
	ELE6-11 are used in GPIO mode, to drive 6 LEDs
	ELE0-5 are used as capacative touch sensors
	Triggering a touch sensor will cause a corresponding LED to illuminate
	
	For desired operation, you may need to play around with TOU_THRESH and REL_THRESH threshold values.
	With default settings, you can brush your fingers across the ELE0-5 pins to trigger the LEDs
	
	The 6 anodes of 2 RGB LEDs are tied to ELE6-11, cathodes tied to ground
	
	Tested on a 3.3V 8MHz Arduino Pro
	A4 (PC4) -> SDA
	A5 (PC5) -> SCL
	D2 (PD2) -> IRQ
*/

#include <avr/io.h>
#include <avr/pgmspace.h>
#include <avr/interrupt.h>
#include "types.h"
#include "defs.h"
#include "i2c.h"
#include "mpr121.h"

#define FOSC 8000000
#define MPR121_R 0xB5	// ADD pin is grounded
#define MPR121_W 0xB4	// So address is 0x5A

#define sbi(var, mask)   ((var) |= (uint8_t)(1 << mask))
#define cbi(var, mask)   ((var) &= (uint8_t)~(1 << mask))

///============Function Prototypes=========/////////////////
char mpr121Read(unsigned char address);
void mpr121Write(unsigned char address, unsigned char data);
void mpr121QuickConfig(void);
void mpr121ViewRegisters(void);
int checkInterrupt(void);

///============Initialize Prototypes=====//////////////////
void ioinit(void);
void delay_ms(uint16_t x);	// this is configured for 16MHz, goes much faster on my 8MHz Arduino

/////=========Global Variables======////////////////////

int main(void)
{
	char touchstatus;
	
	ioinit();
	i2cInit();
	delay_ms(100);
	checkInterrupt();
	
	mpr121QuickConfig();
	
	// Setup the GPIO pins to drive LEDs
	mpr121Write(GPIO_EN, 0xFF);	// 0x77 is GPIO enable
	mpr121Write(GPIO_DIR, 0xFF);	// 0x76 is GPIO Dir
	mpr121Write(GPIO_CTRL0, 0xFF);	// Set to LED driver
	mpr121Write(GPIO_CTRL1, 0xFF);	// GPIO Control 1
	mpr121Write(GPIO_CLEAR, 0xFF);	// GPIO Data Clear
	
	// Blink LEDs to begin
	for (int i = 0; i < 5; i++)
	{
		mpr121Write(GPIO_SET, 0xFF);
		delay_ms(500);
		mpr121Write(GPIO_CLEAR, 0xFF);
		delay_ms(500);
	}
	
	while(1)
	{
		while(checkInterrupt())
			;	// NIRQ will go low when a touch or release occurs, wait till then
		touchstatus = mpr121Read(0x00);	// Read touch status
		mpr121Write(GPIO_CLEAR, 0xFF);	// Clear all LEDs
		touchstatus = touchstatus << 2;	// Shift two bits over
		mpr121Write(GPIO_SET, touchstatus);	// Set LED
	}
}

char mpr121Read(unsigned char address)
{
	char data;
	
	i2cSendStart();
	i2cWaitForComplete();
	
	i2cSendByte(MPR121_W);	// write 0xB4
	i2cWaitForComplete();
	
	i2cSendByte(address);	// write register address
	i2cWaitForComplete();
	
	i2cSendStart();
	
	i2cSendByte(MPR121_R);	// write 0xB5
	i2cWaitForComplete();
	i2cReceiveByte(TRUE);
	i2cWaitForComplete();
	
	data = i2cGetReceivedByte();	// Get MSB result
	i2cWaitForComplete();
	i2cSendStop();
	
	cbi(TWCR, TWEN);	// Disable TWI
	sbi(TWCR, TWEN);	// Enable TWI
	
	return data;
}

void mpr121Write(unsigned char address, unsigned char data)
{
	i2cSendStart();
	i2cWaitForComplete();
	
	i2cSendByte(MPR121_W);	// write 0xB4
	i2cWaitForComplete();
	
	i2cSendByte(address);	// write register address
	i2cWaitForComplete();
	
	i2cSendByte(data);
	i2cWaitForComplete();
	
	i2cSendStop();
}

// MPR121 Quick Config
// This will configure all registers as described in AN3944
// Input: none
// Output: none
void mpr121QuickConfig(void)
{
	// Section A
	// This group controls filtering when data is > baseline.
	mpr121Write(MHD_R, 0x01);
	mpr121Write(NHD_R, 0x01);
	mpr121Write(NCL_R, 0x00);
	mpr121Write(FDL_R, 0x00);
	
	// Section B
	// This group controls filtering when data is < baseline.
	mpr121Write(MHD_F, 0x01);
	mpr121Write(NHD_F, 0x01);
	mpr121Write(NCL_F, 0xFF);
	mpr121Write(FDL_F, 0x02);
	
	// Section C
	// This group sets touch and release thresholds for each electrode
	mpr121Write(ELE0_T, TOU_THRESH);
	mpr121Write(ELE0_R, REL_THRESH);
	mpr121Write(ELE1_T, TOU_THRESH);
	mpr121Write(ELE1_R, REL_THRESH);
	mpr121Write(ELE2_T, TOU_THRESH);
	mpr121Write(ELE2_R, REL_THRESH);
	mpr121Write(ELE3_T, TOU_THRESH);
	mpr121Write(ELE3_R, REL_THRESH);
	mpr121Write(ELE4_T, TOU_THRESH);
	mpr121Write(ELE4_R, REL_THRESH);
	mpr121Write(ELE5_T, TOU_THRESH);
	mpr121Write(ELE5_R, REL_THRESH);
	/*mpr121Write(ELE6_T, TOU_THRESH);
	mpr121Write(ELE6_R, REL_THRESH);
	mpr121Write(ELE7_T, TOU_THRESH);
	mpr121Write(ELE7_R, REL_THRESH);
	mpr121Write(ELE8_T, TOU_THRESH);
	mpr121Write(ELE8_R, REL_THRESH);
	mpr121Write(ELE9_T, TOU_THRESH);
	mpr121Write(ELE9_R, REL_THRESH);
	mpr121Write(ELE10_T, TOU_THRESH);
	mpr121Write(ELE10_R, REL_THRESH);
	mpr121Write(ELE11_T, TOU_THRESH);
	mpr121Write(ELE11_R, REL_THRESH);*/
	
	// Section D
	// Set the Filter Configuration
	// Set ESI2
	mpr121Write(FIL_CFG, 0x04);
	
	// Section E
	// Electrode Configuration
	// Enable 6 Electrodes and set to run mode
	// Set ELE_CFG to 0x00 to return to standby mode
	// mpr121Write(ELE_CFG, 0x0C);	// Enables all 12 Electrodes
	mpr121Write(ELE_CFG, 0x06);		// Enable first 6 electrodes
	
	// Section F
	// Enable Auto Config and auto Reconfig
	/*mpr121Write(ATO_CFG0, 0x0B);
	mpr121Write(ATO_CFGU, 0xC9);	// USL = (Vdd-0.7)/vdd*256 = 0xC9 @3.3V
	mpr121Write(ATO_CFGL, 0x82);	// LSL = 0.65*USL = 0x82 @3.3V
	mpr121Write(ATO_CFGT, 0xB5);*/	// Target = 0.9*USL = 0xB5 @3.3V
}

int checkInterrupt(void)
{
	if ((PIND & (1<<2)) == 0)
		return 0;
	else
		return 1;
}

/*********************
 ****Initialize****
 *********************/
 
void ioinit (void)
{
    //1 = output, 0 = input
	DDRB = 0b01100000; //PORTB4, B5 output
    DDRC = 0b00010011; //PORTC4 (SDA), PORTC5 (SCL), PORTC all others are inputs
    DDRD = 0b11111010; //PORTD (RX on PD0), IRQ on PD2
	PORTC = 0b00110000; //pullups on the I2C bus
}

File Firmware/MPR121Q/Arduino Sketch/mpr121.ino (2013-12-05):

/*Copyright (c) 2010 bildr community

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
 THE SOFTWARE IS PROVIDED "AS IS", WITHOUT WARRANTY OF ANY KIND, EXPRESS OR
 IMPLIED, INCLUDING BUT NOT LIMITED TO THE WARRANTIES OF MERCHANTABILITY,
 FITNESS FOR A PARTICULAR PURPOSE AND NONINFRINGEMENT. IN NO EVENT SHALL THE
 AUTHORS OR COPYRIGHT HOLDERS BE LIABLE FOR ANY CLAIM, DAMAGES OR OTHER
 LIABILITY, WHETHER IN AN ACTION OF CONTRACT, TORT OR OTHERWISE, ARISING FROM,
 OUT OF OR IN CONNECTION WITH THE SOFTWARE OR THE USE OR OTHER DEALINGS IN
 THE SOFTWARE.
*/

#include "mpr121.h"
#include <Wire.h>

int irqpin = 2;  // Digital 2
boolean touchStates[12]; //to keep track of the previous touch states

void setup(){
  pinMode(irqpin, INPUT);
  digitalWrite(irqpin, HIGH); //enable pullup resistor
  
  Serial.begin(9600);
  Wire.begin();

  mpr121_setup();
}

void loop(){
  readTouchInputs();
}


void readTouchInputs(){
  if(!checkInterrupt()){
    
    //read the touch state from the MPR121
    Wire.requestFrom(0x5A,2); 
    
    byte LSB = Wire.read();
    byte MSB = Wire.read();
    
    uint16_t touched = ((MSB << 8) | LSB); //16bits that make up the touch states

    
    for (int i=0; i < 12; i++){  // Check what electrodes were pressed
      if(touched & (1<<i)){
      
        if(touchStates[i] == 0){
          //pin i was just touched
          Serial.print("pin ");
          Serial.print(i);
          Serial.println(" was just touched");
        
        }else if(touchStates[i] == 1){
          //pin i is still being touched
        }  
      
        touchStates[i] = 1;      
      }else{
        if(touchStates[i] == 1){
          Serial.print("pin ");
          Serial.print(i);
          Serial.println(" is no longer being touched");
          
          //pin i is no longer being touched
       }
        
        touchStates[i] = 0;
      }
    
    }
    
  }
}




void mpr121_setup(void){

  set_register(0x5A, ELE_CFG, 0x00); 
  
  // Section A - Controls filtering when data is > baseline.
  set_register(0x5A, MHD_R, 0x01);
  set_register(0x5A, NHD_R, 0x01);
  set_register(0x5A, NCL_R, 0x00);
  set_register(0x5A, FDL_R, 0x00);

  // Section B - Controls filtering when data is < baseline.
  set_register(0x5A, MHD_F, 0x01);
  set_register(0x5A, NHD_F, 0x01);
  set_register(0x5A, NCL_F, 0xFF);
  set_register(0x5A, FDL_F, 0x02);
  
  // Section C - Sets touch and release thresholds for each electrode
  set_register(0x5A, ELE0_T, TOU_THRESH);
  set_register(0x5A, ELE0_R, REL_THRESH);
 
  set_register(0x5A, ELE1_T, TOU_THRESH);
  set_register(0x5A, ELE1_R, REL_THRESH);
  
  set_register(0x5A, ELE2_T, TOU_THRESH);
  set_register(0x5A, ELE2_R, REL_THRESH);
  
  set_register(0x5A, ELE3_T, TOU_THRESH);
  set_register(0x5A, ELE3_R, REL_THRESH);
  
  set_register(0x5A, ELE4_T, TOU_THRESH);
  set_register(0x5A, ELE4_R, REL_THRESH);
  
  set_register(0x5A, ELE5_T, TOU_THRESH);
  set_register(0x5A, ELE5_R, REL_THRESH);
  
  set_register(0x5A, ELE6_T, TOU_THRESH);
  set_register(0x5A, ELE6_R, REL_THRESH);
  
  set_register(0x5A, ELE7_T, TOU_THRESH);
  set_register(0x5A, ELE7_R, REL_THRESH);
  
  set_register(0x5A, ELE8_T, TOU_THRESH);
  set_register(0x5A, ELE8_R, REL_THRESH);
  
  set_register(0x5A, ELE9_T, TOU_THRESH);
  set_register(0x5A, ELE9_R, REL_THRESH);
  
  set_register(0x5A, ELE10_T, TOU_THRESH);
  set_register(0x5A, ELE10_R, REL_THRESH);
  
  set_register(0x5A, ELE11_T, TOU_THRESH);
  set_register(0x5A, ELE11_R, REL_THRESH);
  
  // Section D
  // Set the Filter Configuration
  // Set ESI2
  set_register(0x5A, FIL_CFG, 0x04);
  
  // Section E
  // Electrode Configuration
  // Set ELE_CFG to 0x00 to return to standby mode
  set_register(0x5A, ELE_CFG, 0x0C);  // Enables all 12 Electrodes
  
  
  // Section F
  // Enable Auto Config and auto Reconfig
  /*set_register(0x5A, ATO_CFG0, 0x0B);
  set_register(0x5A, ATO_CFGU, 0xC9);  // USL = (Vdd-0.7)/vdd*256 = 0xC9 @3.3V   set_register(0x5A, ATO_CFGL, 0x82);  // LSL = 0.65*USL = 0x82 @3.3V
  set_register(0x5A, ATO_CFGT, 0xB5);*/  // Target = 0.9*USL = 0xB5 @3.3V
  
  set_register(0x5A, ELE_CFG, 0x0C);
  
}


boolean checkInterrupt(void){
  return digitalRead(irqpin);
}


void set_register(int address, unsigned char r, unsigned char v){
    Wire.beginTransmission(address);
    Wire.write(r);
    Wire.write(v);
    Wire.endTransmission();
}

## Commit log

2013-08-09 Adding board files, code and README
    [MPR121-Breakout-v13.brd, MPR121-Breakout-v13.sch, MPR121-Breakout.brd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]
2013-12-05 Adding Bildr Arduino sketch
2015-08-11 created giant panel v13
    [MPR121-Breakout-Panel-v13.brd]

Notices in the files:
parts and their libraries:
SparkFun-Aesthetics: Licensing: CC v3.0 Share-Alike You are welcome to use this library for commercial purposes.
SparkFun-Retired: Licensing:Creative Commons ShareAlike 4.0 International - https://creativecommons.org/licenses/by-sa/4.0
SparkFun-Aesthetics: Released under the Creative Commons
